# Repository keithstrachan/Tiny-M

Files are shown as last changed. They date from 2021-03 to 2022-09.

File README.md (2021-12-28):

# Tiny-M

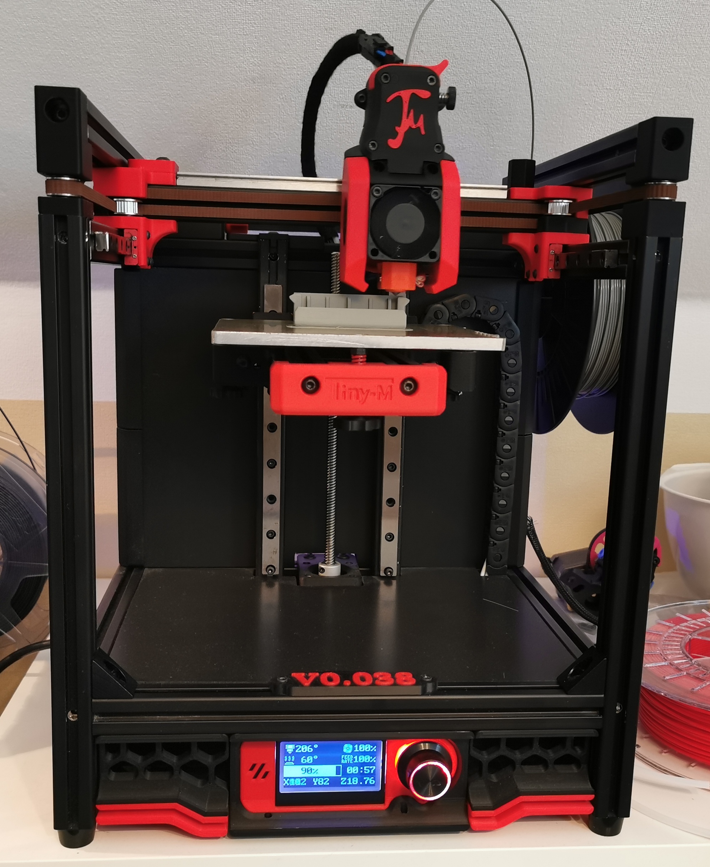
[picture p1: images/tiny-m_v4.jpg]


A compact printer with build volume: 150x150x150 mm

This is a Corona project.  
It is based on [Voron V0](https://github.com/VoronDesign/Voron-0) .  

Bowden and direct drive extruder using [CroXY's Sailfin](https://github.com/CroXY3D/Sailfin-Extruder), [Annex Engineering's Sherpa Mini](https://github.com/Annex-Engineering/Sherpa_Mini-Extruder) or [Bondtech's LGX Lite](https://www.bondtech.se/product/lgx-lite-extruder-custom/) are now available.  

### Current Version is V4:  

Latest source whole printer:  [Tiny-M V4 Onshape](https://cad.onshape.com/documents/1523b676d2485ac19dbd60ec/w/d40ca3d72ed1f4079efb6497/e/a8deb399653e35f8f0a5baa5)

Old source is available at [Tiny-M V3 Onshape](https://cad.onshape.com/documents/d2a24a4147c3d522115f6ea5/w/d8f44be5c0a081fbf527e154/e/debb6c2779e27f86389232d5).

This is my first project of this kind. Maybe something will be missing, is not well documented, or just messy. I apologize for that.  Join the [Discord](https://discord.gg/tmZkjWs) to meet other Tiny-M builders and have your questions answered.

## Why the whole thing?

I had many 3D printer parts in my pocket from my old no longer used printer. 
I cleared out my pocket and took what I had in the box without buying anything new.
After checking all parts, I recognize, that I could build a converted Voron V0 with this parts.

### Hardware

    - 2020 Nut 5 I-Typ alu profiles (6mm wide slot Misumi 2020 will work).  Must have 4.0-4.2mm hole at ends.  B-Typ can work with Helicoils to give a 5mm tapped end.
    - Nema 17 stepper motors
    - 1x 200mm MGN12H for X
    - 2x 200mm MGN9H for Y
    - 2x 200mm MGN12H for Z
    - FYSETC Cheetah V1.1b (TMC2209) or SKR Mini E3 with TMC2209
    - 24V everywhere

### BOM
DRAFT BOM is available now. Thanks to CookieSN!  An updated BOM for V4 is currently in review.

WARNING ! The store Funssor on aliexpress sell a V0 kit with pictures of my Tiny-M. He use picture from github. To be clear IT IS NOT a Tiny-M Kit. Please don't buy it if you want to build a Tiny-M.

### Build Tips
There are 3 versions of the XY-Joins.  V4 is recommended.

- V2 - use 2GT 20T pulleys - No Set Screw Hub
    - The outer diameter of the flanges from the pulleys for XY Joins will not fit.
    - You will need to grind the flanges to fit.
- V3 - use 2GT 20T toothed idler and no M5 Nuts
- V4 - split into 3 parts
    - removed one M5 screw for better alignment
    - optimized belt path to use E3D idler (10mm high) or chinese (9mm high)
    - some design changes
    - more rigid

Parts are best printed out of ABS or ABS+ with 0.4 nozzle with 0.48 extrusion width, 0.2-0.3 layer height, 5 top/bottom layers, 4 perimeters, 40% infill (triangular recommended).  Skirts can be printed out of pretty much any filament type.

There are drill and tapping jigs if you wish to drill and tap your extrusions yourself.  The drilled holes are for blind joints and aren't necessary if using corner brackets.

[Mark Hoy's Excellent Build Log](https://github.com/mark-hoy/tiny-m-build)

[Aku's Build Pix](https://photos.google.com/share/AF1QipNcXcmM3RKy_vv-VFk4SFu25SVPCTLMsn6qd6mMj0eABvdKW5LyGL7gtdgspUF8wQ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)

### User Mods
There are several user mod STLs in the [usermods](https://github.com/gsl12/Tiny-M/tree/master/usermods) directory.

#### V4 Mods
[Belted Z Mod](https://github.com/gsl12/Tiny-M/tree/master/usermods/belted_z_mod)

[190^3 Mod which uses Prusa mini bed plates](https://github.com/gsl12/Tiny-M/tree/master/usermods/190mm_prusa_mini_mod)

[All Metal Bed Undercarriage](https://github.com/gsl12/Tiny-M/tree/master/usermods/all_metal_bed_undercarriage)

[5mm Shoulder Screw Mod, (also works with B-Typ extrusions)](https://github.com/gsl12/Tiny-M/tree/master/usermods/shoulder_screw_mod)

[5mm Dowel Pin Mod](https://github.com/gsl12/Tiny-M/tree/master/usermods/5mm_idler_pins)

[Rear Cable Guide](https://github.com/gsl12/Tiny-M/tree/master/usermods/rear_cable_guide)

[Tophat Mod](https://www.prusaprinters.org/prints/64115-tiny-m-voron0-mod-tophead) - Note, an official tophat is in development.

#### V3 Mods
[Xile's Sherpa Direct Drive Toolhead](https://github.com/Annex-Engineering/Sherpa_Mini-Extruder/tree/master/Toolheads/Xile_Tiny_M)

[Ocho Camino's Sailfin Direct Drive Toolhead](https://github.com/CroXY3D/Sailfin-Extruder)

### Discord

The [CroXY Discord](https://discord.gg/tmZkjWs) has a tiny-m channel where several Tiny-M builders hang out.  Be sure to check the #tiny-m-faq channel

# Images

V3  



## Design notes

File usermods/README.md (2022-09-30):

### User mods

* tiny-m_tap_guide.stl : guide for tapping ends of 2020 extrusions (danielfmo)
* tiny-m_drill_guide.stl: drill guide for blind joint acccess holes (danielfmo)
* ab_drive_top_raised.STL : On some steppers the screws bottom out.  This thickens the plastic. (Xile)
* Knob_Wrench.stl : Tool to turn the tensioning knobs (Xile)
* Panel_Holder_1.STL : Panel holders keep panels from sagging - (Xile, modified from design by Anlin at Annex Engineering)
* PanelClip_v2_1.stl : Hold exterior panels on - (Xile, Modified from design by Anlin at Annnex Engineering)
* front_bed_mount_proud_text.stl : (Ocho Camino) Front of bed with text raised so you can do a filament swap.
* LRS-150_Mount.STL : Mount for Meanwell power supply (Xile)
* SKR_Mini_Mount.STL : Mount for SKR Mini (Xile)
* Raspi_Mount.STL : Mount for Raspberry Pi (Xile)
* Buck_Converter_Mount.STL : Mount for [Buck converter](https://smile.amazon.com/gp/product/B07N3QT628/ref=ppx_yo_dt_b_search_asin_title?ie=UTF8&psc=1]) for Raspberry Pi 5V (Xile) 
* Cover_No_Logo.STL : No logo version of screen cover
* door_handle: A handle for the enclosure door

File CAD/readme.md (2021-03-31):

# Current Version is V4:  

latest source whole printer:  [Tiny-M V4 Onshape](https://cad.onshape.com/documents/1523b676d2485ac19dbd60ec/w/d40ca3d72ed1f4079efb6497/e/a8deb399653e35f8f0a5baa5)

V4 folder includes separated CAD files for each V4 part.

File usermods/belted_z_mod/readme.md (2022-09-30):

### Belted Z Mod for 150mm and 190mm Tiny-M

@quasi

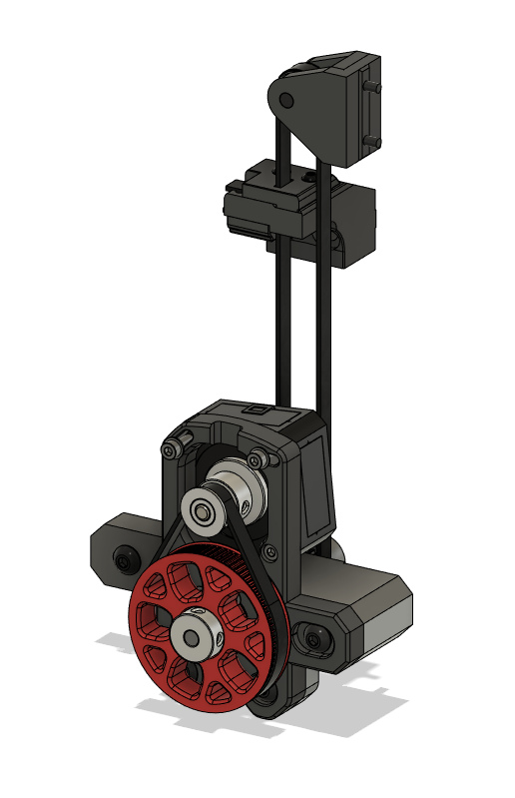
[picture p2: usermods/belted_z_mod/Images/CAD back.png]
Back


Modified from V0 belted z mod for Tiny-M printer, 2020 extrusions, and to upgrade some bolts from M3 to M5.

CAD shows a printed 80T gear because I copied that over from the V0 belted z files, but I used a metal 80T gear.

The M5x20mm screws need to be BHCS for clearance with 80T gear, but all other bolts can be either SHCS or BHCS.

Print the Bottom Frame Bracket 190.stl version if using this on a 190mm^3 Tiny-M

[sample printer.cfg changes](https://github.com/gsl12/Tiny-M/blob/master/usermods/belted_z_mod/beltedzstepper.cfg.txt)

#### BOM (US Sources)
##### Electronics	
- LDO NEMA17 42STH20-1004ASH	[PrintedSolid](https://www.printedsolid.com/collections/motors/products/ldo-nema-17-high-temp-voron-ldo-42sth20-1004ashvrn)  other 20 or a 25mm stepper 0.9 or 1.8 deg should work
##### Motion	
- F695-2RS Bearing [Amazon](https://www.amazon.com/F695-2RS-Bearing-5x13x4mm-Miniature-Bearings/dp/B07VMJLXLH)
- 1x 5mm shaft	78 mm	- I recommend measuring for yourself	[Amazon](https://www.amazon.com/Sydien-100mm-Solid-Stainless-Airplane/dp/B083LDBTLD)
- 1x 2GT Belt Loop (6mm wide) 188mm			[AliExpress](https://www.aliexpress.com/item/4000397043382.html)
- 1x 2GT Open Belt LL-2GT-6 (6mm wide) 10M			[AliExpress](https://www.aliexpress.com/item/32853559638.html)
- 1x 2GT 20T Pulley 6mm, 5mm Bore			[AliExpress](https://www.aliexpress.com/item/32995102911.html)
- 1x 2GT 16T Pulley 6mm, 5mm bore			[Amazon](https://www.amazon.com/gp/product/B01IMPM44O)
- 1x 2GT 80T Pulley 6mm, 5mm Bore			[AliExpress](https://www.aliexpress.com/item/32782605159.html)
- 1x 2GT 20T Toothed Idler 6mm, 5mm Bore		Alternate to 2 F695-2RS bearings	[AliExpress](https://www.aliexpress.com/item/32726309946.html) or better quality: [AliExpress](https://www.aliexpress.com/item/33023133633.html)
#### Hardware	
- Xx 5x10x0.5 Shim Ring			[AliExpress](https://www.aliexpress.com/item/32917948919.html) Qty as necessary.  
- 1x M3x5x4 Heatset Inserts		[AliExpress](https://www.aliexpress.com/item/4000232858343.html?spm=a2g0s.9042311.0.0.21164c4dGhWHhY)
- 2x M3 roll in T-nuts		[AliExpress](https://www.aliexpress.com/item/32805163712.html)
- 4x M5 roll in T-nuts			[AliExpress](https://www.aliexpress.com/item/32805163712.html)
- 2x M3 washer			
- 1x M5x40 SHCS			
- 3x M5x20 BHCS		These NEED to be BHCS for clearance with the 80T gear, all others can be SHCS or BHCS interchangeably	
- 1x M5x16 BHCS			
- 3x M3x12 SHCS			
- 1x M3x20 SHCS

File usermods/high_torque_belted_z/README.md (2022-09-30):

### High Torque Belted Z

- @AgentL3r#0333

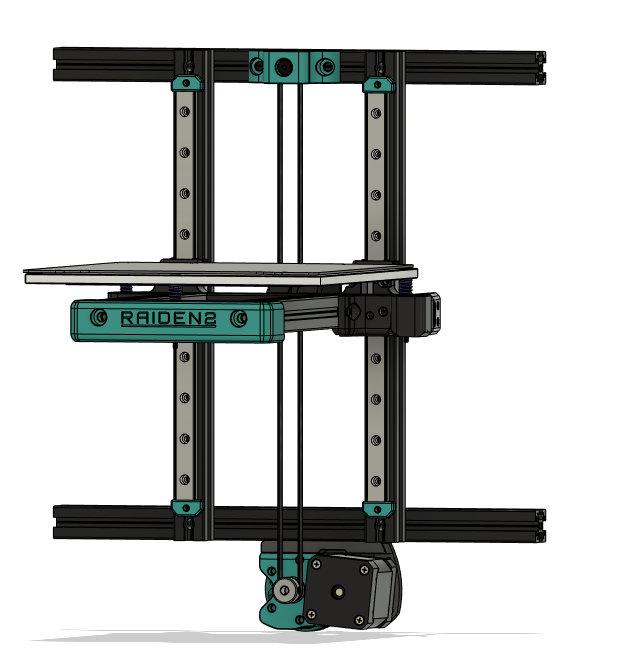
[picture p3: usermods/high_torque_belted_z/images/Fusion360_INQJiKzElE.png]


## Features and Rationale
- Allows for any size of NEMA17 motor to be used, increasing versatility and mitigates the need for slimline/pancake motors 
- Motors with higher detent torques can be used to prevent bed drop on power loss (after 4:1 gearing)
- Gearbox is mounted under the electronics enclosure leading to more space for electronics mounting
- Compatible with both 190mm³ and 150mm³ builds **MUST USE MODIFIED PARTS BY nehiLo#1732**
- Shoulder screw compatible upper z idler
- Arguably less Z artifacting due to no leadscrew
  
## Bill of Materials

Fasteners
- M3x5x4 mm threaded insert x5
- M3 washer (1mm) x3
- M3 shim (0.5mm) x3
- M3x6 BHCS x4
- M3x10 SHCS x4
- M3x20 SHCS x6
- M5 t-nut x7
- M5x10 BHCS x4
- M5x20 BHCS x2
- M5x28 BHCS OR M5x16 SHOULDER SCREW with 5mm shoulder x1
- M5x60 dowel pin

Motion
- F695-2RS bearing x2
- 20T 2GT pulley x2
- 80T 2GT pulley x1 (CAN ALSO USE PRINTED VORON M4 80T)
- 188mm 2GT 6mm belt loop
- some 2GT 6mm belt
- 20T 5mm bore idler

Electronics
- NEMA17 motor

## Assembly
It is best to refer to the CAD  model for guidance on how to build this system.

**Gearbox:**
Insert the four heatset inserts into the back of the shaft guide and press-fit the F695-2RS bearing as follows:
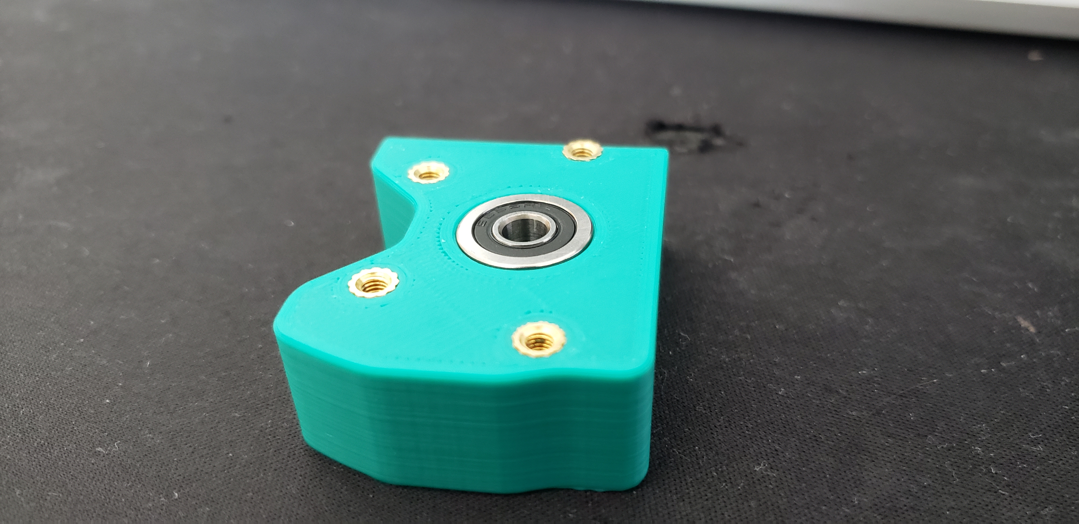
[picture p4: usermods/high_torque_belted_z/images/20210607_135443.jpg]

Press fit an F695-2RS bearing onto the motor plate.

Attach the motor plate to the bottom of the 2020 extrusion on your printer using two M5x10mm screws and two M5 t-nuts. Ensure you use the flat edge and a pair of calipers to correctly position the motor plate so that the pin is centered.

Attach the shaft guide using four M3x20 screws.

Insert the 5x60mm shaft through the motor plate and shaft guide, ensuring it spins freely in the bearings.

The pulleys can now be attached:

80T pulley --> printed spacer --> F695-2RS --> F695-2RS  --> 0.5mm shim --> 20T pulley

Tighten all grub screws.

Insert the remaining 20T pulley onto the shaft of the NEMA17 motor. Screw the motor to the motor plate using M3x10 screws (not fully tight as you'll need the motor to swivel for tension) and an M3 washer. During this, ensure the belt loop wraps around the 20T and 80T pulley. You can now tension the pulley and fully tighten all motor mounting screws. The gearbox is now complete.

**Idler:**
The upper idler is simple to assemble with a 20T idler sandwiched between two 0.5mm shims. Attach this to the top 2020 extrusion as per the CAD model.

**Tensioner:**
Insert the final heatset insert into the hole at the TOP of the tensioner.

Attach the tensioner to the back of the Z carriage using the M5x20mm screws and two M5 t-nuts. Positioning at this point isn't important.

Insert the two M3x20 screws into the tensioner. At this point, you can route the belt. 

The belt will wrap around the M3x20 screws so that the teeth indexes with itself, creating a very secure hold. Place the printed block in the center of the tensioner with the hole facing up.

Using the M3x6mm screws, secure the backplate.

Finally, use an M3x10 screw to tension the belt by pressing the printed block.

This assembly is fiddly and takes a while to get assembled - especially the belt tension. The system works very well and has given me excellent results.

Double check your spacing for everything prior to turning on the system - refer to the CAD if in doubt.

For any questions, feel free to get in touch with me on the TinyM Discord.

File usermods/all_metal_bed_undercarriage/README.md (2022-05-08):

### All Metal Bed Undercarriage

- @Ocho Camino

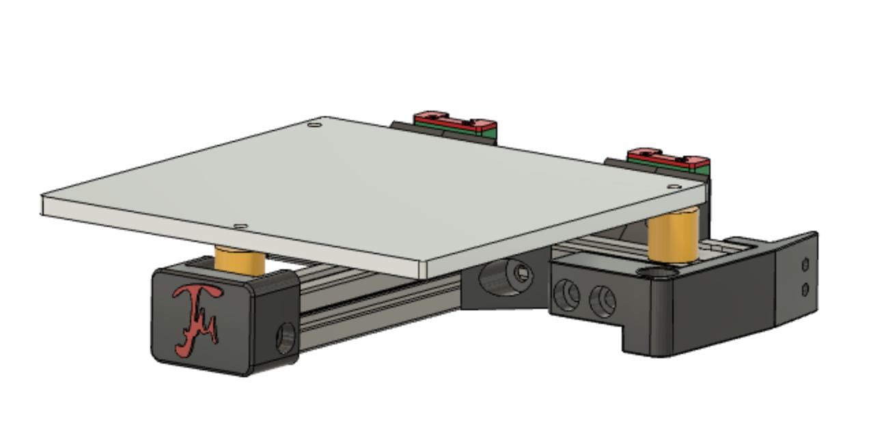
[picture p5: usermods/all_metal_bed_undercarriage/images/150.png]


## Rationale
The existing bed mounts are made of ABS and flex somewhat.   Making the entire bed undercarriage out of metal greatly reduces this flex.

## Status

  Alpha.  Still testing.  There could be some changes.
  
## BOM

150mm Bed:
- 1x HFSB5-2020-160-AH80-AV10-BV150
- 1x HFSB5-2020-160 (with 4 3mm clearance holes drilled for the MGN12 mount screws. Use MGN12_drill_jig.stl)
- 1x HFSB5-2020-133-RTP-AV10 (Misumi). 

190mm Bed:
- 1x HFSB5-2020-200-AH100-AV10-BV190 
- 1x HSFB5-2020-200 (with 4 3mm clearance holes drilled for the MGN12 mount screws.  Use MGN12_drill_jig.stl)
- 1x HFSB5-2020-173-RTP-AV10

Common:
- 6x Openbuilds Angle Brackets [Openbuilds](https://openbuildspartstore.com/black-angle-corner-connector/) [Ali Express](https://www.aliexpress.com/item/32899575950.html)
- 3x 16mm long silicone bed mounts [Amazon](https://smile.amazon.com/dp/B07RZKF8MB?psc=1&ref=ppx_yo2_dt_b_product_details)
- 3x Bed Adjusters (reuse existing) [Ali Experss Style B or D](https://www.aliexpress.com/item/4000421280308.html)
- 3x 45mm (or 50mm) FHCS screws.  45s protrude only 2.3 mm below the extrusion, so 50 is probably better.
- 4x M3 washers (at least 6mm OD) - [ALT Ali Bling](https://www.aliexpress.com/item/32968161596.html)
- 4x M3x8 SHCS (might need M3x10 with the Alt Ali Bling)
- 11x M5x6 BHCS
- 1x M5x12 SHCS
- 1x M5x16 SHCS

## Assembly

Print the parts (ok, it's not all metal, but the load bearing parts are). The nosepiece can be printed with a filament swap for a contrasting color for the logo.  

Note the rear two holes on the bed are in slightly different positions than on stock Tiny-M.  They are 12mm from the rear.
Use the template (TBD) to drill the two countersunk M3 holes.   

The underbed assembly is made of 3 pieces of 2020.  The rear piece attaches to the MGN12 cars.  The middle piece sisters to the rear piece and also supports the bed at each end in the rear.  The front piece is the forward pointing spar that supports the bed at the middle in the front.

The rear 2020 piece will need to be drilled with 4 3mm clearance holes to attach it to the MGN12 car.  Use the MGN12_drill_jig.stl to drill these holes, from each side of the 2020.

If you ordered the other 2020 parts without Misumi drilling for you, you will need to use the drill guide. The middle 2020 that is is sistered to the rear 2020 piece needs a 3mm vertical clearance hole 10mm from each end, and a 5mm horizontal clearance hole 30mm from each end (middle_front_drill_jig.stl).   Additionally that piece needs a 5mm horiztonal clearance hole centered on the extrusion - use middle_jig.stl centered on the extrusion.

The front piece is tapped M5 at the rear and has a 3mm clearance hole drilled vertically 10mm from the front of it (middle_front_drill_jig.stl).

Assemble the middle and front spar 2020 pieces to form a tee.   The two angle brackets that support the forward spar can be any type of angle bracket. Make sure this connection is solid and doesn't twist or flex.   Attach the spar to the tapped hole with a M3x8 BHCS for more rigidity. 

The Openbuilds corner brackts screw into the top screw holes of the MGN12H cars. Attach them to the rear 2020 piece.  The rear 2020 is attached to the lower screw holes of the MGN12H car via M3x16 SHCS.

Attach the tee piece to the rear piece with 2 M5x6 BHCS

The rest of the parts assembly should be straightforward.

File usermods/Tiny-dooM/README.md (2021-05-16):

### Tiny-dooM

- @Ocho Camino

An outer enclosure around the Tiny-M printer.  This has only been designed in CAD.  Nothing has been done IRL.

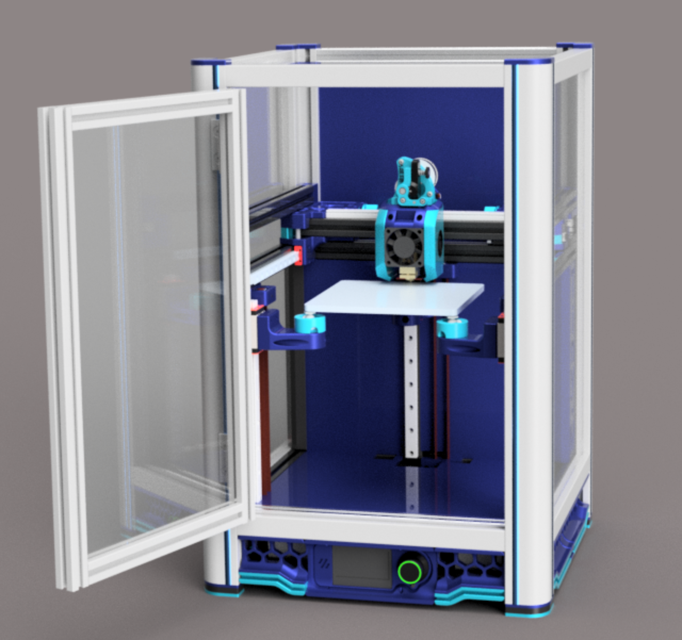
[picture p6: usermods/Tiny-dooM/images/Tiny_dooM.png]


#### BOM

Nothing is changed from the default Tiny-M BOM.  However you will need to drill 2 blind joint access holes in the 4 z corner extrusions.  Those holes should be approx 30mm from the ends and face fore and aft.  They are used to attach the Tiny-M to the dooM frame.

For a 190^3 Tiny-dooM add 50mm to every extrusion length

- 4x HFSR5-404020-500 Corner Posts
- Non-smooth faced extrusion option
  - 8x HFS5-2020-260 Top and bottom horizontals
  - 2x HFS5-2020-217 Front door horizontals
  - 2x HFS5-2020-408 Front door verticals
- Smooth faced extrusion option
  - 2x HFS5-2020-260 Top and bottom rear horizontals (Slots exposed for mounting things)
  - 3x HFSF5-2020-260 - Bottom front, left and right horizontals
  - 3x HFST5-2020-260 - Top front, left and right horizontals
  - 2x HFSF5-2020-217 Front door horizontals
  - 2x HFSF5-2020-408 Front door verticals - you will need to drill holes for hinges and handle
- 2x Hinges [Zyltech](https://www.zyltech.com/aluminum-swing-door-hinge-for-20mm-extrusion-w-mounting-hardware/) alt: HHPNL5-SST hinges
- 24x Internal Corner Brackets [Zyltech](https://www.zyltech.com/t-slot-l-type-90-degree-2020-inside-bracket-12-pack/)
- Door Catch TBD
- Optional: Ninjaflex or similar TPU for feet

Total Hardware Cost for 150 Tiny-dooM (no panels): ~$85

#### Printed Parts

- 4x Top trim pieces
- 4x Feet.  Optionally print black portion using Ninjaflex or similar TPU by filament swap.  Use XX% infill
- TBD Panel retention:  Double pane?  In slot or slight inset from frame?

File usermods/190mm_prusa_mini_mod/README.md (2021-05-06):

### 190^3 Build volume which can use the Prusa Mini Bed Plate.

- @Ocho Camino & @AgentL3r
- Skirts by @AgentL3r

The changes for a 190^3 build volume are fairly simple.   
- All frame extrusions need to be 50mm longer
   * 11x 2020 310mm  (note one more than normal Tiny-M.  This is used as a cross brace about halfway up in the front to stiffen the frame)
   * 4x	2020 350mm
   * 2x	2020 300mm
- All bed extrusions need to be 40 mm longer
   * 3x	2020 170mm
- 1X 250mm MGN12H for X (RobotDigg SUS 440C highly recommended) 
- 2x 250mm MGN9H for Y 
- 2X 250mm MGN12H for Z
- 250mm TR8x4 leadscrew
- Mic6 bed should be 190x190x6mm.  Template for drilling are in the STLs subdir here.
- Bed heater should be 150x150mm.   [Keenovo or AliExpress](https://www.aliexpress.com/item/4000271859036.html?spm=a2g0s.9042311.0.0.27424c4dSLLDSs)
- Three parts need to be 40mm wider.  The front nosepiece and the upper and lower Z supports.  They are in the STLs subdir here
- Skirts are changed.  STLs and CAD by @AgentL3r are here

Note that the nosepiece is modded with proud text, so you can print it text up and do a filament swap for contrasting text.  The holes in the nosepiece have a membrane for printability that must be drilled out 5mm.

If you wish to use blind holes, the extrusion BOM:
- 2x HFSB5-2020-170-TPW		Z carriage.
- 1x HFSB5-2020-170-AH40-BH130	 Z carriage. 
- 2x HFSB5-2020-300-LCV-RCV		Vertical extrusions.
- 1x HFSB5-2020-310	X axis extrusion. 
- 3x HFSB5-2020-310-TPW	Lower front and upper left/right extrusions. 
- 4x HFSB5-2020-310-TPW-AH274		Left and right extrusions. 
- 2x HFSB5-2020-310-TPW-AH93.5-BH216.5	Horizontal Z extrusions.
- 2x HFSB5-2020-350-TPW-RCH-AP60		Front vertical extrusions. 
- 2x HFSB5-2020-350-TPW-RCH-AH60		Rear vertical extrusions.

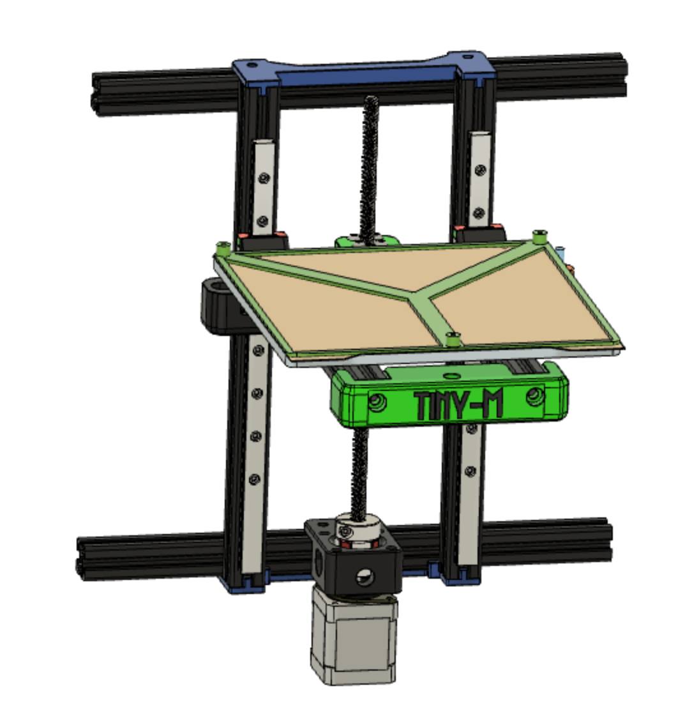
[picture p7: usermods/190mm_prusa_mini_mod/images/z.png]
190^3 Z Assembly


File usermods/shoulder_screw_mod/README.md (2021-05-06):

### Shoulder Screw Mod

by Ocho Camino

This is a mod to use shoulder screws instead of regular metric screws as the shafts for the idlers to ride upon.  

#### Rationale

Shoulder screws are machined to specified dimensions vs screws which are undersized and often have a rough surface.  With undersized screws the contact area of the screw to the inner race of the bearing is much less (ideally a line), creating excessive Hertzian contact stress.  This is hard on the bearing and can create imprecision in the motion of the machine.

#### Description

This mod either uses Misumi 5mm shoulder screws which have M3 threads on the end, or McMaster or other shoulder screws which have M4 threads.  The thread lengths are important on the McMaster M4 version, so if substituting other sources you may need to remove some thread if it's too long and bottoms out.

On the four corners of Tiny-M the ends of the 2020s are tapped M5 for M5 screws.  If using Misumi shoulders, you will need thread adapters.   If using M4 shoulders you will need M4 Helicoils

Print the replacement parts in the STL directory here.

Total cost of this mod is about $25-$30.

#### MISUMI M3 THREADED SHOULDERS
  * 6x 5mmx30 Shoulder Screws M3 Threads, Misumi [SMSB5-30](https://us.misumi-ec.com/vona2/detail/110300249140/?ProductCode=SMSB5-30)
  * 4x 5mmx20 Shoulder Screws M3 Threads, Misumi [SMSB5-20](https://us.misumi-ec.com/vona2/detail/110300249140/?ProductCode=SMSB5-20)
  * 4x M3-M5 308 Type Thread Adapters, AliExpress [M3-M5 308](https://www.aliexpress.com/item/32817733610.html)
  * 2x M3 Tee Nuts

Print the replacement parts, except the M4 versions in the STL directory here.  Install the thread adapters on the 4 M5x30 shoulder screws and secure with Loc-Tite.   These may then be threaded into the tapped M5 hole on the end of the 2020 vertical corner extrusions.  The Tee nuts accept the shoulder screw for the front idler on the AB drives
 
#### FILASTRUDER OR MCMASTER M4 THREADED SHOULDERS
  * 4x 5mmx30 Shoulder Screws, 5-9mm long M4 threads for corners, [Filastruder](https://www.filastruder.com/products/shoulder-screws-bolts?_pos=1&_sid=c5a60b2bd&_ss=r&variant=32520243380295) or [McMaster 92981A055](https://www.mcmaster.com/92981A055/)
  * 2x 5mmx30 Shoulder Screws 5mm long M4 threads for AB drives, [Filastruder](https://www.filastruder.com/products/shoulder-screws-bolts?_pos=1&_sid=c5a60b2bd&_ss=r&variant=32520243380295) or [McMaster 90278A376](https://www.mcmaster.com/90278A376/)
  * 4x 5mmx20 Shoulder Screws, 5-9mm long M4 threads for XY Joins, [Filastruder](https://www.filastruder.com/products/shoulder-screws-bolts?_pos=1&_sid=c5a60b2bd&_ss=r&variant=16712533868615) or [McMaster 92981A042](https://www.mcmaster.com/92981A042/)
  * 1x M4 Helicoil kit, AliExpress [M4x0.7](https://www.aliexpress.com/item/4001157165014.html) or [McMaster 91732A946](https://www.mcmaster.com/91732A946/)
  * 2x M4 Tee Nuts

Print the replacement parts (the M4 versions) in the STL directory here.  Install M4 helicoils in the 4 corner 2020 extrusions.   The Tee nuts accept the shoulder screw for the front idler on the AB drives 

#### EU Folks using 20x20 B-type groove 6 and M4 THREADED SHOULDERS
  * 4x 5mmx30 Shoulder Screws, 8mm long M4 threads for corners, Drasse [460119196](https://www.drabbe.nl/p/iso-7379-5-m4-30/100351/)
  * 2x 5mmx25 Shoulder Screws 8mm long M4 threads for AB drives, Drasse [460119221](https://www.drabbe.nl/p/iso-7379-5-m4-25/100350/)
  * 4x 5mmx20 Shoulder Screws, 8mm long M4 threads for XY Joins Drasse [460119215](https://www.drabbe.nl/p/iso-7379-5-m4-20/100349/)
  * 4x M4-M6 308 Type Thread Adapters, AliExpress [M4-M6 308](https://www.aliexpress.com/item/32817733610.html)
  * 2x M4 Tee Nuts

Print the replacement parts, except the M4 versions in the STL directory here.  Install the thread adapters on the 4 M5x30 shoulder screws and secure with Loc-Tite.   These may then be threaded into the tapped M6 hole on the end of the 2020 B-type groove 6 vertical corner extrusions. The Tee nuts accept the shoulder screw for the front idler on the AB drives

Note, the 5mm shoulders with M4 threads can be sourced from China.  [one possible source - not verified](https://www.aliexpress.com/item/1005001698010943)

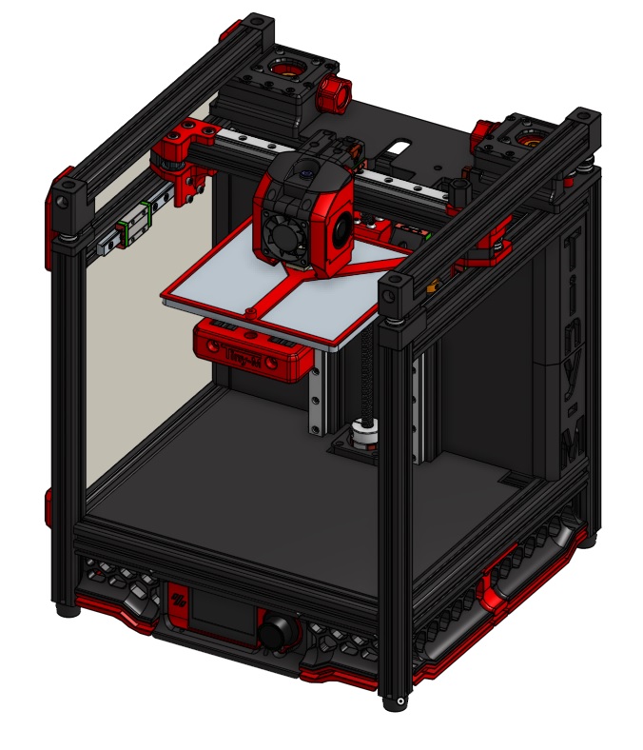
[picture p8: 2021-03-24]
images/CAD_V4.jpg

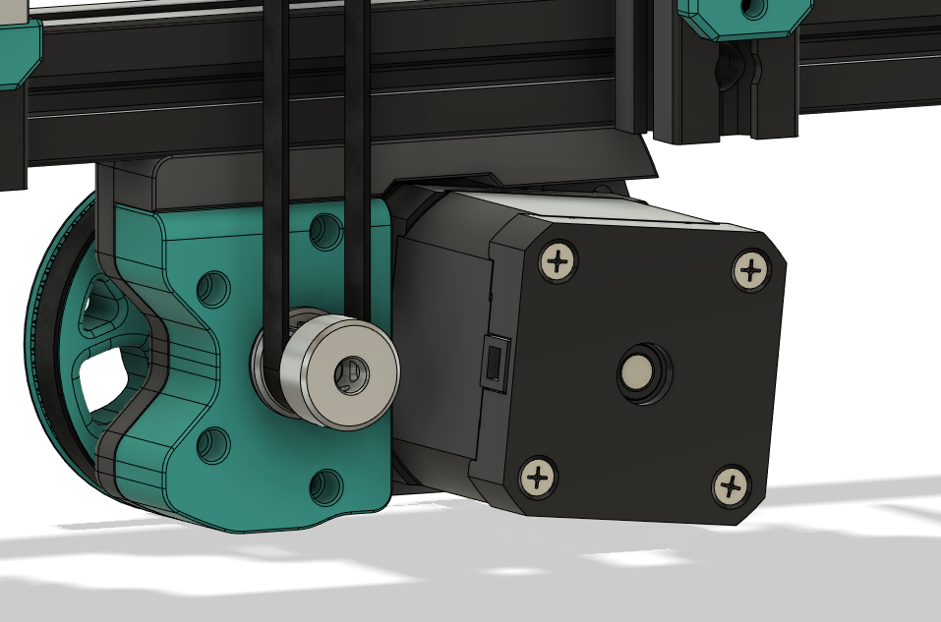
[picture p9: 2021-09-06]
usermods/high_torque_belted_z/images/Fusion360_5fomUjJK1f.png

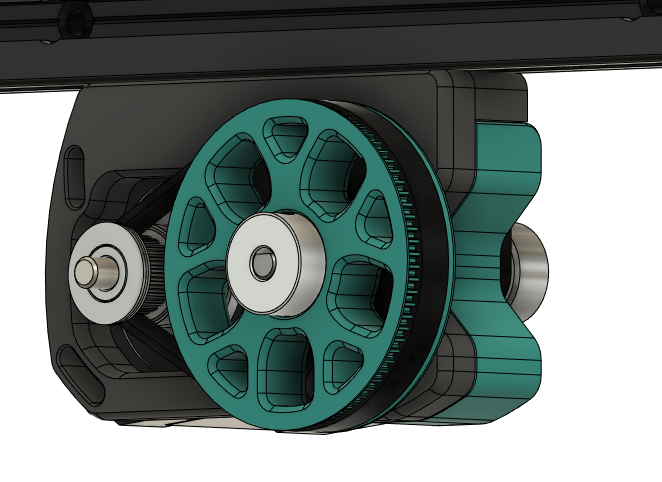
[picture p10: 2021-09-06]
usermods/high_torque_belted_z/images/Fusion360_azjq1ihh6n.png

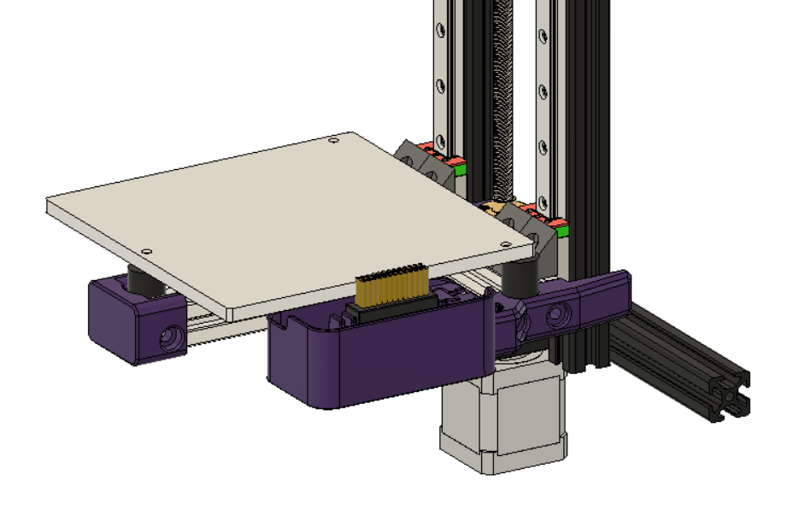
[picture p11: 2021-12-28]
usermods/almost_all_metal_undercarriage_with_purge_bucket/Images/cad_image.png

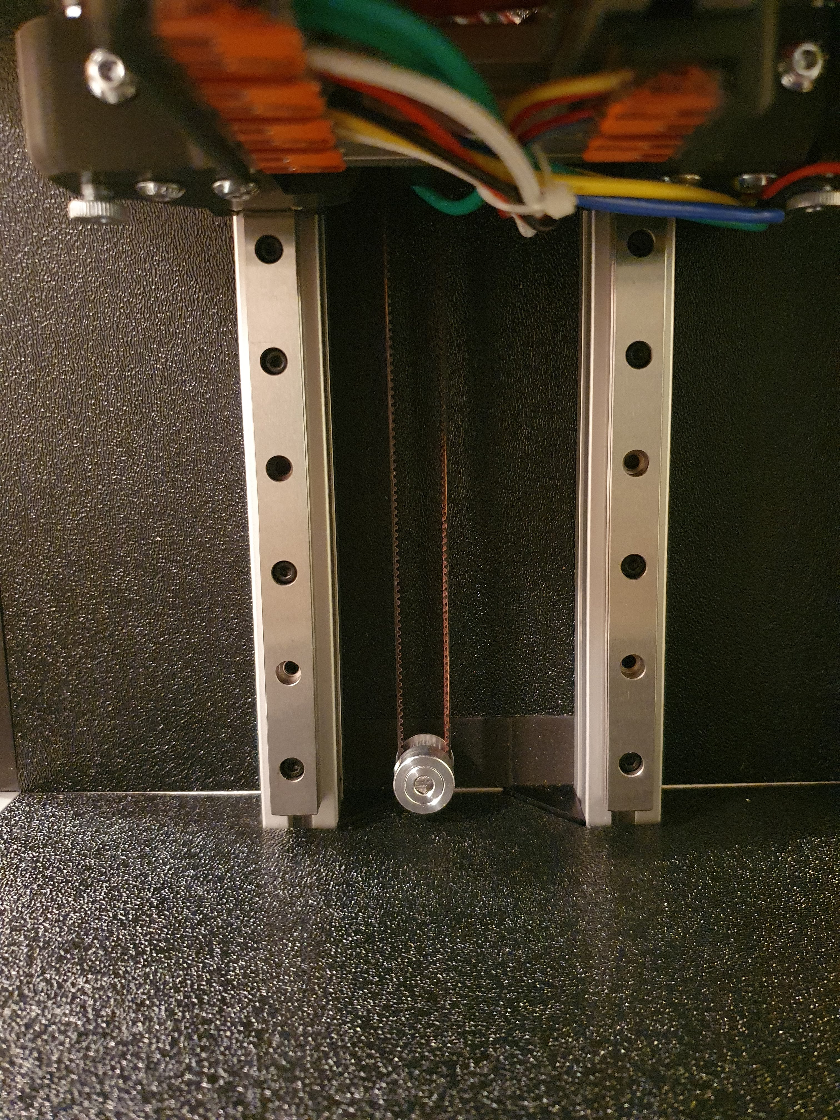
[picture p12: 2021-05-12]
usermods/belted_z_mod/Images/Under bed.jpg

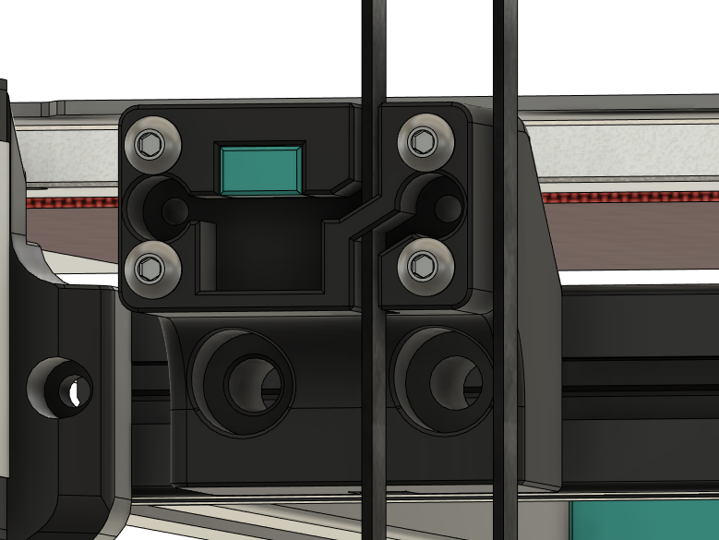
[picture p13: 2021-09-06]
usermods/high_torque_belted_z/images/Fusion360_2svyNtLjEN.png

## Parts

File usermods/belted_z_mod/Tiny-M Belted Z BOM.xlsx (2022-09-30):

 | Component | Quantity | Notes | Vendor (US) | Link (US)
Electronics | LDO NEMA17 42STH20-1004ASH | 1 |  | PrintedSolid | https://www.printedsolid.com/collections/motors/products/ldo-nema-17-high-temp-voron-ldo-42sth20-1004ashvrn
Motion | F695-2RS Bearing | 5 |  | Amazon | https://www.amazon.com/F695-2RS-Bearing-5x13x4mm-Miniature-Bearings/dp/B07VMJLXLH
 | 5mm shaft | 78 mm | I recommend measuring for yourself | Amazon | https://www.amazon.com/Sydien-100mm-Solid-Stainless-Airplane/dp/B083LDBTLD?s=hi
 | GT2 Belt Loop (6mm wide) 188mm | 1 |  | AliExpress | https://www.aliexpress.com/item/4000397043382.html
 | GT2 Open Belt LL-2GT-6 (6mm wide) - 10M | 1 |  | AliExpress | https://www.aliexpress.com/item/32853559638.html
 | GT2 20T Pulley 6mm, 5mm Bore | 1 |  | AliExpress | https://www.aliexpress.com/item/32995102911.html
 | GT2 16T Pulley 6mm, 5mm bore | 1 |  | Amazon | https://www.amazon.com/gp/product/B01IMPM44O/ref=ppx_yo_dt_b_asin_title_o05_s00?ie=UTF8&psc=1
 | GT2 80T Pulley 6mm, 5mm Bore | 1 |  | AliExpress | https://www.aliexpress.com/item/32782605159.html
 | GT2 20T Toothed Idler 6mm, 5mm Bore | 1 | Alternate to 2 F695-2RS bearings | AliExpress | https://www.aliexpress.com/item/32726309946.html
Hardware | 5x10x0.5 Shim Ring | Varies |  | AliExpress | https://www.aliexpress.com/item/32917948919.html
 | M3x5x4 Heatset Inserts | 1 |  | AliExpress | https://www.aliexpress.com/item/4000232858343.html?spm=a2g0s.9042311.0.0.21164c4dGhWHhY
 | M3 roll in T-nuts | 2 |  | AliExpress | https://www.aliexpress.com/item/32805163712.html
 | M5 roll in T-nuts | 4 |  | AliExpress | https://www.aliexpress.com/item/32805163712.html
 | M3 washer | 2
 | M5x40 SHCS | 1
 | M5x20 BHCS | 3 | These NEED to be BHCS for clearance with the 80T gear, all others can be SHCS or BHCS interchangeably
 | M5x16 BHCS | 1
 | M3x12 SHCS | 3
 | M3x20 SHCS | 1

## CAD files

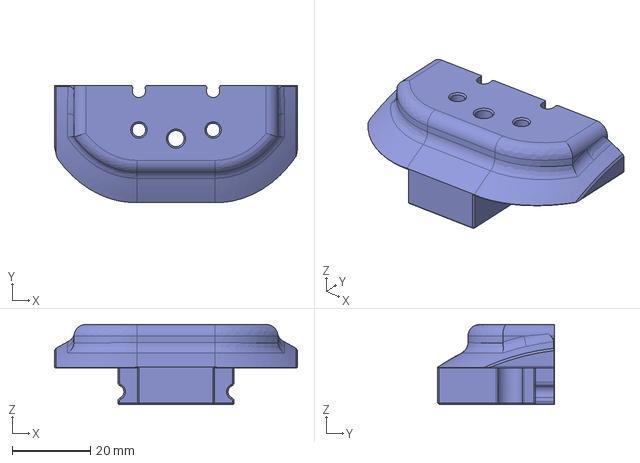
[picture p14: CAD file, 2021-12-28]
CAD/V4/bw_dd_sch_wing_v12_lgx_lite.step
62.2 x 30.0 x 20.5 mm

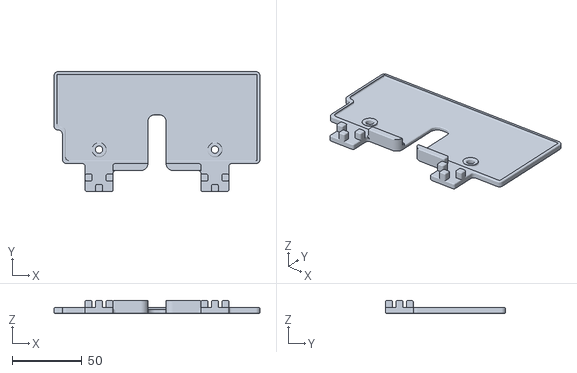
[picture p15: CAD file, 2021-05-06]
STLs/essentials/Bed/z_positioner_upper.stl
147.6 x 86.0 x 9.00

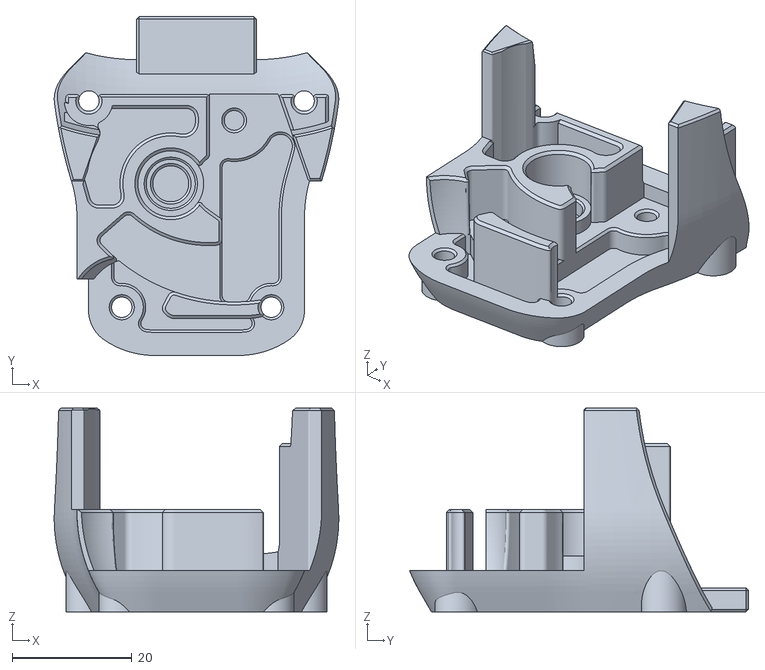
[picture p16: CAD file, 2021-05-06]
STLs/essentials/Gantry/X_Axis/X_Carriage/mini_AB_parts/printed_parts_MGN12_v4 - mini_ab - front_logo.stl
47.6 x 56.7 x 34.0

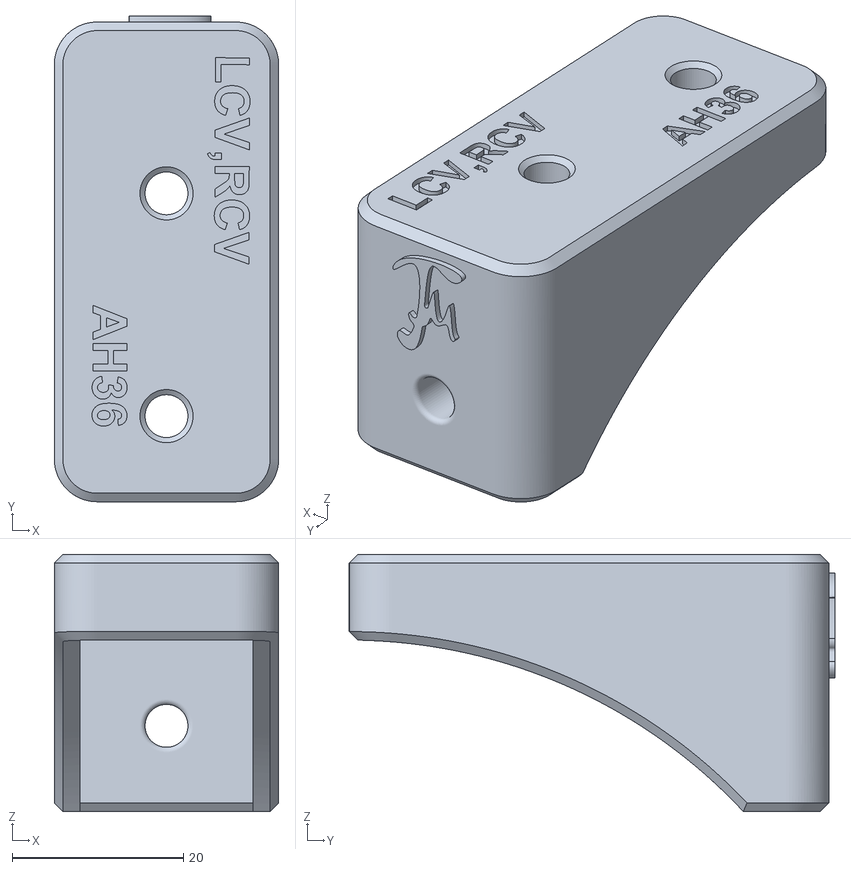
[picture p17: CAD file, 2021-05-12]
STLs/essentials/Tools/Drill_Tap_Jig_B_.stl
26.2 x 56.7 x 30.0

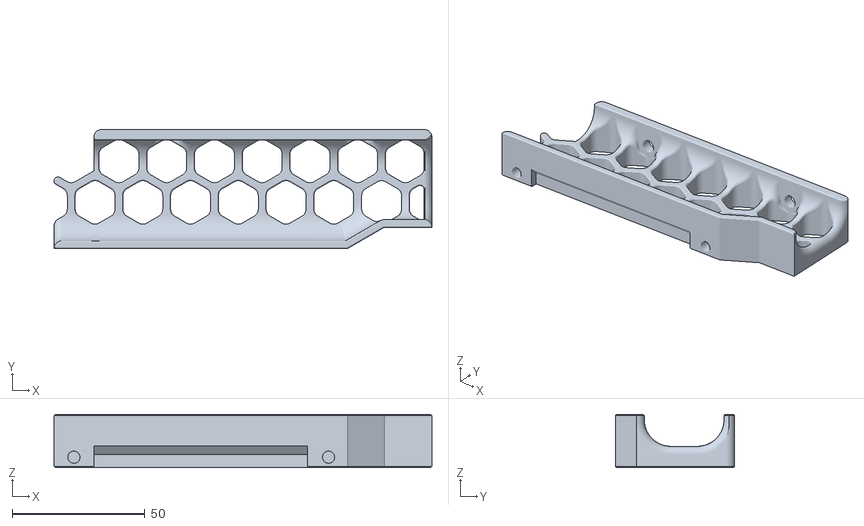
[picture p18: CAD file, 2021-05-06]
usermods/190mm_prusa_mini_mod/STLs/skirt_side_right_x2.stl
142.5 x 44.9 x 20.0

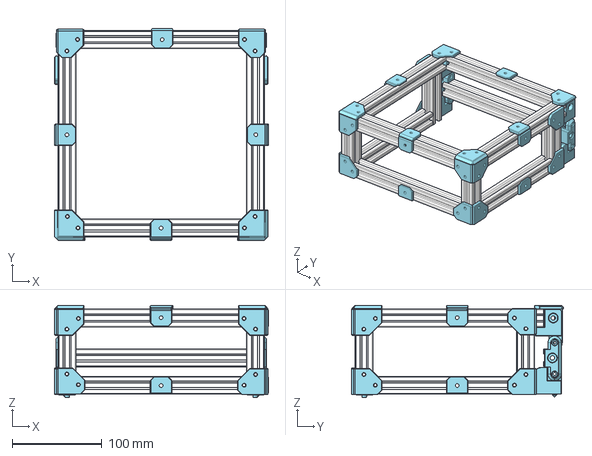
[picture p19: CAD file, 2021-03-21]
usermods/2020_Hinged_TopHat_Print/2020_Hinged_TopHat_CAD.step
238.7 x 236.5 x 103.1 mm

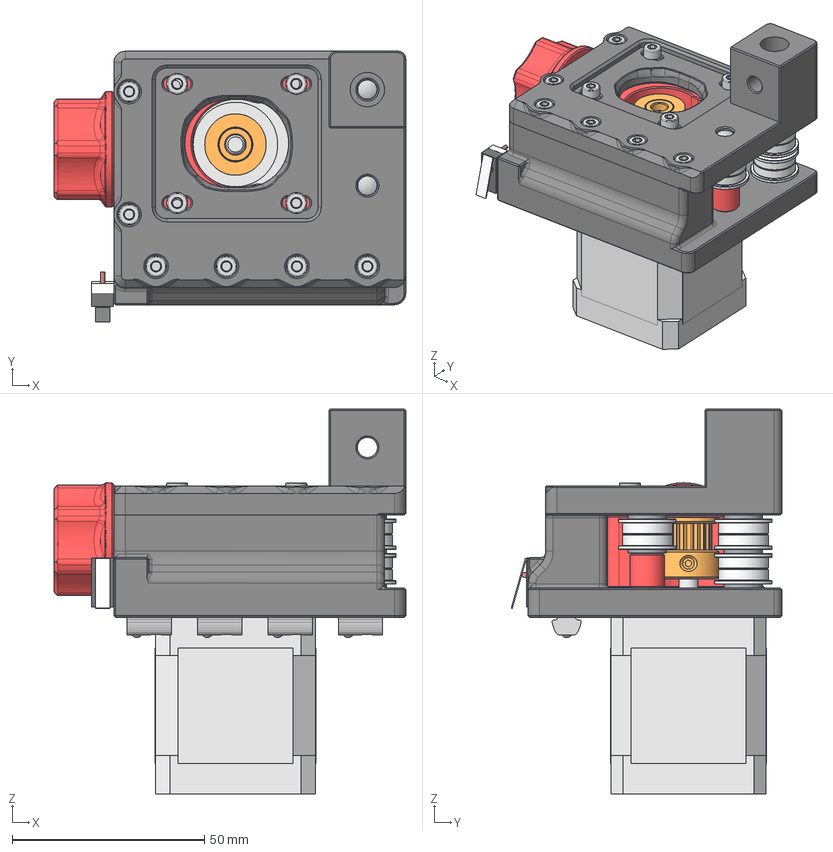
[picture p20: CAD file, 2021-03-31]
usermods/5mm_idler_pins/CAD/ab_drive_unit_right_V4 v4.step
91.5 x 70.4 x 100.2 mm
DIN 912 M3x35 x 8
M3-T-Nut x 4
DIN 912 M3x30 x 2
F695-2RS x 6
DIN 988 5x10x1 Shim Ring x 5
b_drive_right_bottom_V4
DIN 934 M3 x 2
D2F-5L
Motor 17HS19-2004S
GT2_20T
[a]_b_drive_right_tensioner_V4
[a]_b_drive_knop_V4
[a]_ab_drive_spacer_9mm
b_drive_right_top_V4
91595A376_32mm_METRIC ALLOY STEEL DOWEL PIN x 2

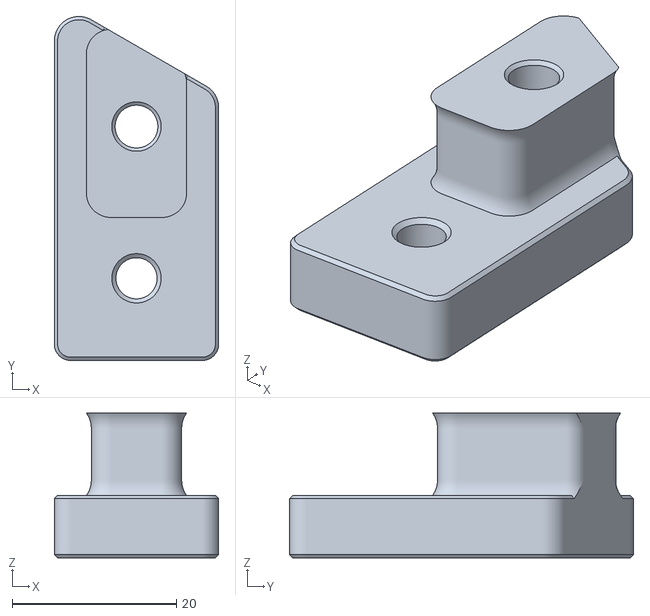
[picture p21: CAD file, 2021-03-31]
usermods/5mm_idler_pins/STL/front_idler_left_bottom_V4.stl
20.0 x 41.8 x 17.6

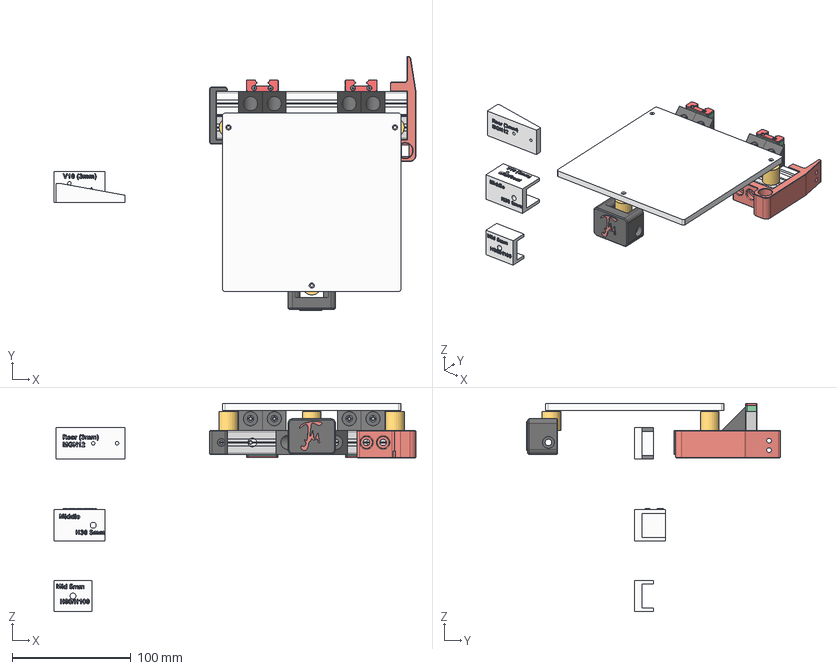
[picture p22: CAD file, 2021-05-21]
usermods/all_metal_bed_undercarriage/CAD/150mm.step
304.4 x 213.7 x 175.0 mm
Bed
MGN12H, LINEAR GUIDE BLOCK x 2
Silicone Bed Spacer
End Cap
Nameplate
HFSB5-2020-160-LCV-RCV-AH30-BH80-CH130
HFSB5-2020-160-Drilled
Z Touch and Chain Mount
Jigs

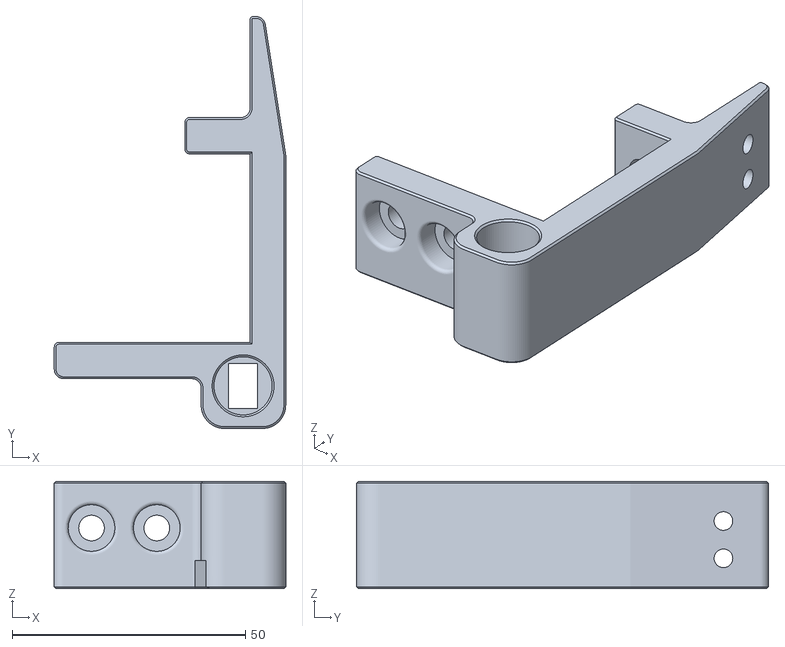
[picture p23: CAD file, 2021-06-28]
usermods/all_metal_bed_undercarriage/STL/Z_Touch_and_Chain_Mount.stl
49.6 x 88.3 x 23.0

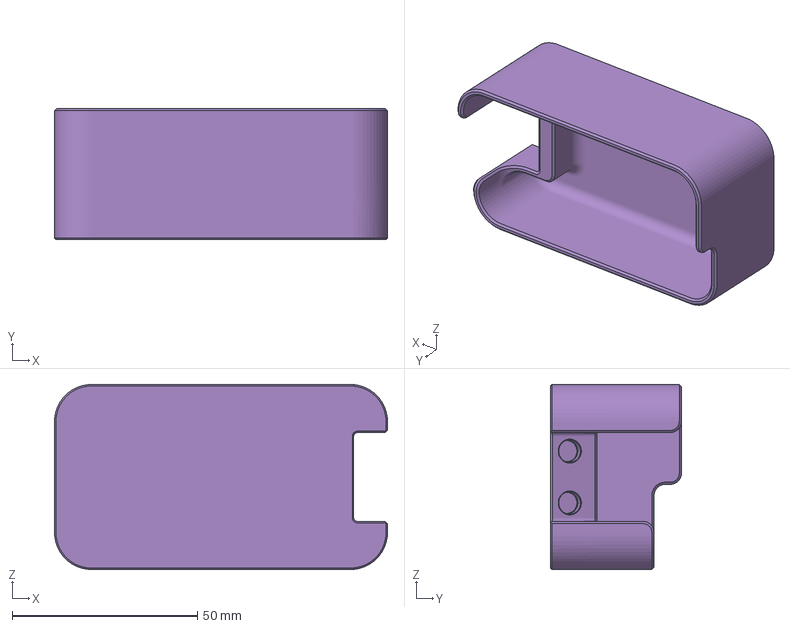
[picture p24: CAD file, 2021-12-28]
usermods/almost_all_metal_undercarriage_with_purge_bucket/STLs/brush_bucket.3mf
90.0 x 35.4 x 50.0 mm

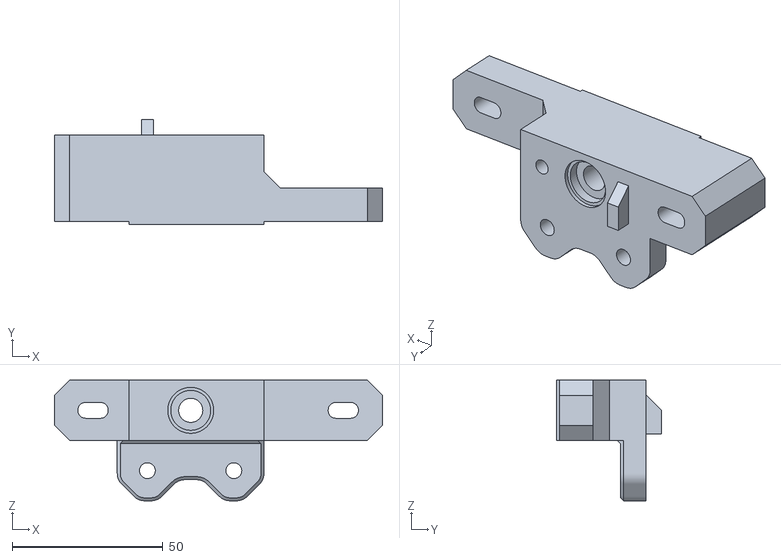
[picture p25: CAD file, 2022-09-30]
usermods/belted_z_mod/STLs/Bottom Frame Bracket.stl
108.8 x 34.7 x 40.0

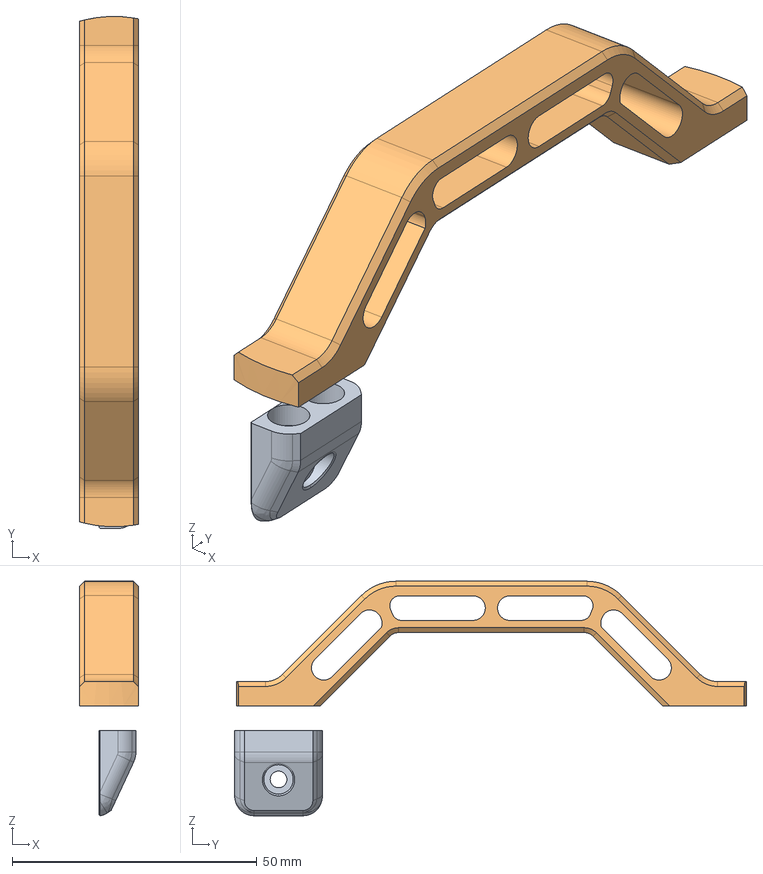
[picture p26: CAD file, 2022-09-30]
usermods/door_handle/CAD/TinyM Handle v3.step
12.0 x 104.6 x 47.9 mm
Door_Latch
Door_Handle

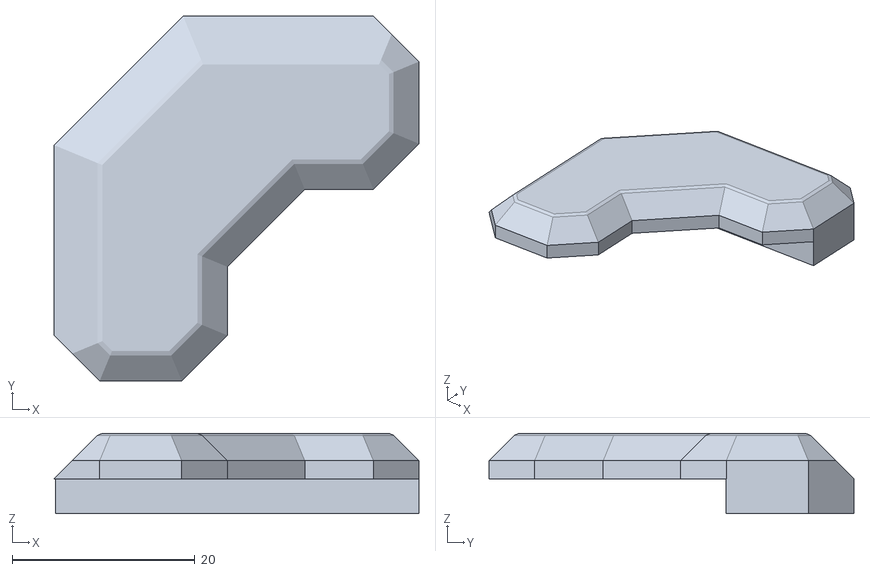
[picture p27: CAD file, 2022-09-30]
usermods/door_handle/stl/corner_door_flat(Mirror).stl
40.0 x 40.0 x 8.80

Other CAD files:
STLs/essentials/Gantry/X_Axis/X_Carriage/printed_parts_MGN12_v4 - bw_dd_sch_wing_lgx_lite.stl
usermods/DrillGuides/tiny-m_drill_guide.step.step
usermods/front_bed_mount_proud_text.stl
usermods/high_torque_belted_z/STLs/150mm ver/beltztens150.stl
CAD/V3/ass_x_carriage_E3DV6.step
CAD/V4/Drill Tap Jigs v4.f3d
CAD/V4/Drill Tap Jigs v4.step
STLs/essentials/Bed/z_position_lower.stl
STLs/essentials/Gantry/X_Axis/X_Carriage/mini_AB_parts/printed_parts_MGN12_v4 - bw_dd_sch_wing_mini_ab.stl
STLs/essentials/Gantry/X_Axis/X_Carriage/mini_AB_parts/printed_parts_MGN12_v4 - mini_ab - front.stl
STLs/essentials/Gantry/X_Axis/X_Carriage/mini_AB_parts/printed_parts_MGN12_v4 - mini_ab - guidler.stl
STLs/essentials/Gantry/X_Axis/X_Carriage/mini_AB_parts/printed_parts_MGN12_v4 - mini_ab - latch.stl
STLs/essentials/Gantry/X_Axis/X_Carriage/mini_AB_parts/printed_parts_MGN12_v4 - mini_ab - latch_shuttle.stl
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

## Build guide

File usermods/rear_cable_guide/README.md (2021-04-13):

Trimp pieces and guide for the rear umbilical cable.   By @aku

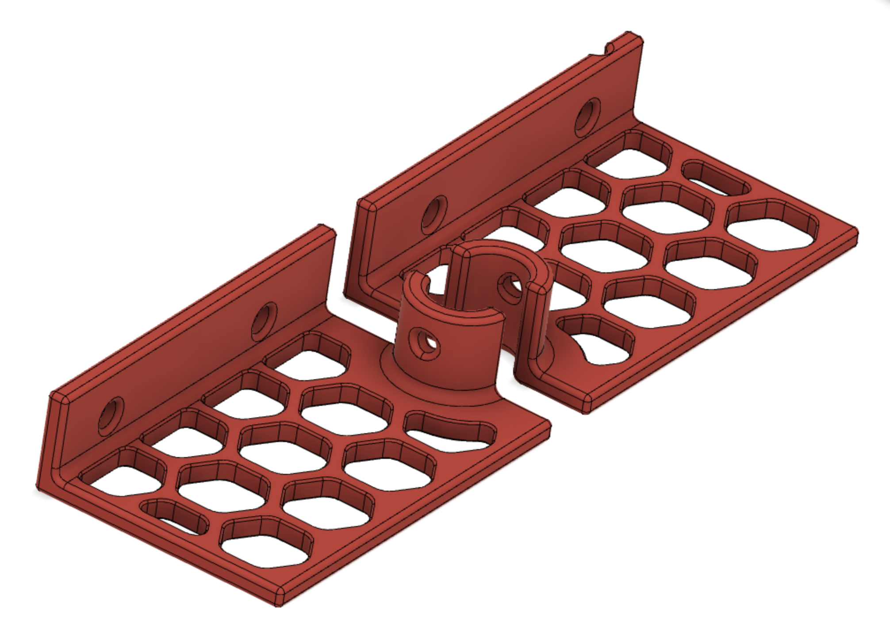
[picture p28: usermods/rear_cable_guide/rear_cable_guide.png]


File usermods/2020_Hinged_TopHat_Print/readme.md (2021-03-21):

DON'T USE THESE YET.  THEY ARE NOT SIZED FOR TINYM.

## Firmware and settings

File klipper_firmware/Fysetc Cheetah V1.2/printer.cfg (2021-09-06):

# This file contains common pin mappings for the Fysetc Cheetah v1.2b
# board. To use this config, the firmware should be compiled for the
# STM32F103 with "No bootloader" and serial (on USART1 PA10/PA9)
# communication.

# The "make flash" command does not work on the Cheetah. Instead,
# after running "make", run the following command to flash the board:
#  stm32flash -w out/klipper.bin -v -i rts,-dtr,dtr /dev/ttyUSB0

# See docs/Config_Reference.md for a description of parameters.


[mcu]
serial: /dev/serial/by-id/usb-1a86_USB2.0-Serial-if00-port0
restart_method: cheetah

[stepper_x]
step_pin: PB8
dir_pin: !PB9
enable_pin: !PA8
microsteps: 16
full_steps_per_rotation: 400
rotation_distance: 40
endstop_pin: ^PA1
position_endstop: 153
position_max: 154
position_min: -3
homing_speed: 50

[tmc2208 stepper_x]
uart_pin: PA12
tx_pin: PA11
run_current: 1.00
hold_current: 0.500
stealthchop_threshold: 999999

[stepper_y]
step_pin: PB2
dir_pin: !PB3
enable_pin: !PB1
microsteps: 16
full_steps_per_rotation: 400
rotation_distance: 40
endstop_pin: ^PB4
position_endstop: 152.5
position_max: 152.5
position_min:-3
homing_speed: 50

[tmc2208 stepper_y]
uart_pin: PB7
tx_pin: PB6
run_current: 1.00
hold_current: 0.500
stealthchop_threshold: 999999

[stepper_z]
step_pin: PC0
dir_pin: PC1
enable_pin: !PC2
microsteps: 16
full_steps_per_rotation: 400
rotation_distance: 4
endstop_pin: ^PA15
#position_endstop: 0
position_max: 140
position_min: -3
homing_speed: 50

[tmc2208 stepper_z]
uart_pin: PB11
tx_pin: PB10
run_current: 1.00
hold_current: 0.500
stealthchop_threshold: 999999

[extruder]
step_pin: PC15
dir_pin: !PC14
enable_pin: !PC13
microsteps: 16
full_steps_per_rotation: 200 
rotation_distance: 4.077670766928368
nozzle_diameter: 0.400
filament_diameter: 1.750
heater_pin: PC6
sensor_type: EPCOS 100K B57560G104F
sensor_pin: PC4
#control: pid
#pid_kp: 21.527
#pid_ki: 1.063
#pid_kd: 108.982
min_temp: 0
max_temp: 270
max_extrude_only_distance: 780.0
max_extrude_cross_section: .8
Pressure_advance: 0.04665
pressure_advance_smooth_time: 0.040

[tmc2208 extruder]
uart_pin: PA3
tx_pin: PA2
run_current: 0.30
hold_current: 0.250
stealthchop_threshold: 999999

[heater_bed]
heater_pin: PC7
sensor_type: NTC 100K MGB18-104F39050L32
sensor_pin: PC5
#control: pid
#pid_kp: 54.027
#pid_ki: 0.770
#pid_kd: 948.182
min_temp: 0
max_temp: 130

[fan]
pin: PC8

[heater_fan nozzle_cooling_fan]
pin: PB0

[idle_timeout]
timeout: 180000

[homing_override]
axes: xyz
set_position_z: 0
gcode:
   G90
   G0 Z5 F600
   G28 X Y
   G0 X153 Y132 F3600 
   
   G28 Z
   G0 Z10 F1800
   G0 X75 Y75 Z20 F3600


[virtual_sdcard]
path: ~/uploads/

[pause_resume]

[display_status]

[gcode_macro CANCEL_PRINT]
rename_existing: BASE_CANCEL_PRINT
gcode:
    TURN_OFF_HEATERS
    CLEAR_PAUSE
    SDCARD_RESET_FILE
    BASE_CANCEL_PRINT

[gcode_macro CANCEL_PRINT]
rename_existing: BASE_CANCEL_PRINT
gcode:
    TURN_OFF_HEATERS
    CLEAR_PAUSE
    SDCARD_RESET_FILE
    BASE_CANCEL_PRINT

[gcode_macro PRINT_START]
#   Use PRINT_START for the slicer starting script - please customise for your slicer of choice
gcode:
    M140 S{BED}
    G28                            ; home all axes
    G1 Z20 F3000                   ; move nozzle away from bed
    # Wait for bed to reach temperature
    M190 S{BED}
    # Set and wait for nozzle to reach temperature
    M109 S{EXTRUDER}


   
[gcode_macro PRINT_END]
#   Use PRINT_END for the slicer ending script - please customise for your slicer of choice
gcode:

    M400                           ; wait for buffer to clear
    G92 E0                         ; zero the extruder
    G1 E-4.0 F3600                 ; retract filament
    G91                            ; relative positioning

    #   Get Boundaries
    {% set max_x = printer.configfile.config["stepper_x"]["position_max"]|float %}
    {% set max_y = printer.configfile.config["stepper_y"]["position_max"]|float %}
    {% set max_z = printer.configfile.config["stepper_z"]["position_max"]|float %}

    #   Check end position to determine safe direction to move
    {% if printer.toolhead.position.x < (max_x - 20) %}
        {% set x_safe = 20.0 %}
    {% else %}
        {% set x_safe = -20.0 %}
    {% endif %}

    {% if printer.toolhead.position.y < (max_y - 20) %}
        {% set y_safe = 20.0 %}
    {% else %}
        {% set y_safe = -20.0 %}
    {% endif %}

    {% if printer.toolhead.position.z < (max_z - 2) %}
        {% set z_safe = 2.0 %}
    {% else %}
        {% set z_safe = max_z - printer.toolhead.position.z %}
    {% endif %}

    G0 Z{z_safe} F3600    ; move nozzle up
    G0 X{x_safe} Y{y_safe} F20000    ; move nozzle to remove stringing
    TURN_OFF_HEATERS
    M107                           ; turn off fan
    G90                            ; absolute positioning
    G0 X75 Y{max_y} F3600          ; park nozzle at rear


[printer]
kinematics: corexy
max_velocity: 500
max_accel: 5000
max_z_velocity: 5
max_z_accel: 100

[board_pins]
aliases:
    # EXP1 header
    EXP1_1=PC9,  EXP1_3=PC11, EXP1_5=PC10, EXP1_7=PB12, EXP1_9=<GND>,
    EXP1_2=PC12, EXP1_4=PB14, EXP1_6=PB13, EXP1_8=PB15, EXP1_10=<5V>
    # Pins EXP1_4, EXP1_8, EXP1_6 are also MISO, MOSI, SCK of bus "spi2"

# See the sample-lcd.cfg file for definitions of common LCD displays.

#*# <---------------------- SAVE_CONFIG ---------------------->
#*# DO NOT EDIT THIS BLOCK OR BELOW. The contents are auto-generated.
#*#
#*# [extruder]
#*# control = pid
#*# pid_kp = 22.562
#*# pid_ki = 0.912
#*# pid_kd = 139.601
#*#
#*# [heater_bed]
#*# control = pid
#*# pid_kp = 58.047
#*# pid_ki = 3.172
#*# pid_kd = 265.564
#*#
#*# [stepper_z]
#*# position_endstop = -0.700
#*#
#*# [input_shaper]
#*# shaper_type_x = ei
#*# shaper_freq_x = 84.0
#*# shaper_type_y = zv
#*# shaper_freq_y = 71.8

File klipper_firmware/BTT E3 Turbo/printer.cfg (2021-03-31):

# This file contains common pin mappings for the BIGTREETECH SKR E3
# Turbo. To use this config, the firmware should be compiled for the
# LPC1769.

# See docs/Config_Reference.md for a description of parameters.

[stepper_x]
step_pin: P1.4
dir_pin: !P1.8
enable_pin: !P1.0
microsteps: 16
full_steps_per_rotation: 400
rotation_distance: 40
endstop_pin: ^P1.29
position_endstop: 153
position_max: 154
position_min: -3
homing_speed: 50

[tmc2209 stepper_x]
uart_pin: P1.1
#diag_pin: P1.29
run_current: 1.0
hold_current: 0.800
stealthchop_threshold: 99999

[stepper_y]
step_pin: P1.14
dir_pin: !P1.15
enable_pin: !P1.9
microsteps: 16
full_steps_per_rotation: 400
rotation_distance: 40
endstop_pin: ^P1.28
position_endstop: 152.5
position_max: 152.5
position_min:-3
homing_speed: 50

[tmc2209 stepper_y]
uart_pin: P1.10
#diag_pin: P1.28
run_current: 1.0
hold_current: 0.800
stealthchop_threshold: 99999

[stepper_z]
step_pin: P4.29
dir_pin: P4.28
enable_pin: !P1.16
microsteps: 16
full_steps_per_rotation: 400
rotation_distance: 4
endstop_pin: ^P1.27
position_endstop: -.95
position_max: 140
position_min: -1
homing_speed: 10

[tmc2209 stepper_z]
uart_pin: P1.17
#diag_pin: P1.27
run_current: 1.0
hold_current: 0.800
stealthchop_threshold: 99999

[extruder]
step_pin: P2.6
dir_pin: !P2.7
enable_pin: !P0.4
microsteps: 16
full_steps_per_rotation: 400
rotation_distance: 8.28121601732
nozzle_diameter: 0.400
filament_diameter: 1.750
heater_pin: P2.3
sensor_type: EPCOS 100K B57560G104F
sensor_pin: P0.24
#control: pid
#pid_Kp: 21.527
#pid_Ki: 1.063
#pid_Kd: 108.982
min_temp: 0
max_temp: 270
max_extrude_only_distance: 780.0
max_extrude_cross_section: .8
Pressure_advance: 0.04
pressure_advance_smooth_time: 0.040

[tmc2209 extruder]
uart_pin: P0.5
#diag_pin: P1.26
run_current: 0.30
hold_current: 0.250
stealthchop_threshold: 99999


[heater_bed]
heater_pin: P2.5
#keenovo pad
sensor_type:  NTC 100K MGB18-104F39050L32  
sensor_pin: P0.25
smooth_time: 3.0
max_power: 0.8
#control: pid
#pid_Kp: 54.027
#pid_Ki: 0.770
#pid_Kd: 948.182
min_temp: 0
max_temp: 130

[fan]
pin: P2.2

[heater_fan nozzle_cooling_fan]
pin: P2.1

[idle_timeout]
timeout: 180000

[homing_override]
axes: xyz
set_position_z: 0
gcode:
   G90
   G0 Z5 F600
   G28 X Y
   G0 X153 Y132 F3600 
   
   G28 Z
   G0 Z10 F1800
   G0 X75 Y75 Z20 F3600

[mcu]
serial: /dev/serial/by-id/usb-Klipper_lpc1769_1680FF01A49869AFACCE3E5EC02000F5-if00

[printer]
kinematics: corexy
max_velocity: 500
max_accel: 2000
max_z_velocity: 10
max_z_accel: 30
square_corner_velocity: 5.0

[virtual_sdcard]
path: ~/uploads/

[pause_resume]

[display_status]

[gcode_macro CANCEL_PRINT]
rename_existing: BASE_CANCEL_PRINT
gcode:
    TURN_OFF_HEATERS
    CLEAR_PAUSE
    SDCARD_RESET_FILE
    BASE_CANCEL_PRINT

[gcode_macro PRINT_START]
#   Use PRINT_START for the slicer starting script - please customise for your slicer of choice
gcode:
    M140 S{BED}
    G28                            ; home all axes
    G1 Z20 F3000                   ; move nozzle away from bed
    # Wait for bed to reach temperature
    M190 S{BED}
    # Set and wait for nozzle to reach temperature
    M109 S{EXTRUDER}


   
[gcode_macro PRINT_END]
#   Use PRINT_END for the slicer ending script - please customise for your slicer of choice
gcode:

    M400                           ; wait for buffer to clear
    G92 E0                         ; zero the extruder
    G1 E-4.0 F3600                 ; retract filament
    G91                            ; relative positioning

    #   Get Boundaries
    {% set max_x = printer.configfile.config["stepper_x"]["position_max"]|float %}
    {% set max_y = printer.configfile.config["stepper_y"]["position_max"]|float %}
    {% set max_z = printer.configfile.config["stepper_z"]["position_max"]|float %}

    #   Check end position to determine safe direction to move
    {% if printer.toolhead.position.x < (max_x - 20) %}
        {% set x_safe = 20.0 %}
    {% else %}
        {% set x_safe = -20.0 %}
    {% endif %}

    {% if printer.toolhead.position.y < (max_y - 20) %}
        {% set y_safe = 20.0 %}
    {% else %}
        {% set y_safe = -20.0 %}
    {% endif %}

    {% if printer.toolhead.position.z < (max_z - 2) %}
        {% set z_safe = 2.0 %}
    {% else %}
        {% set z_safe = max_z - printer.toolhead.position.z %}
    {% endif %}

    G0 Z{z_safe} F3600    ; move nozzle up
    G0 X{x_safe} Y{y_safe} F20000    ; move nozzle to remove stringing
    TURN_OFF_HEATERS
    M107                           ; turn off fan
    G90                            ; absolute positioning
    G0 X75 Y{max_y} F3600          ; park nozzle at rear
	
[gcode_macro LOAD_FILAMENT]
gcode:
   M83                            ; set extruder to relative
   G1 E280 F1800                  ; quickly load filament to down bowden
   G1 E30 F300                    ; slower extrusion for hotend path
   G1 E15 F150                    ; prime nozzle with filament
   M82                            ; set extruder to absolute
    
[gcode_macro UNLOAD_FILAMENT]
gcode:
   M83                            ; set extruder to relative
   G1 E10 F300                    ; extrude a little to soften tip
   G1 E-380 F1800                 ; retract filament completely
   M82                            ; set extruder to absolute
   
   
[gcode_macro PAUSE]
rename_existing: BASE_PAUSE
default_parameter_X: 230    # edit to your preferred park position
default_parameter_Y: 230    # edit to your preferred park position
default_parameter_Z: 10     # edit to your preferred park position
default_parameter_E: 1      # edit to your preferred retract length
gcode:
    SAVE_GCODE_STATE NAME=PAUSE_state
    BASE_PAUSE
    G91
    G1 E-{E} F2100
    G1 Z{Z}
    G90
    G1 X{X} Y{Y} F6000
    
[gcode_macro RESUME]
rename_existing: BASE_RESUME
default_parameter_E: 1      # edit to your preferred retract length
gcode:
    G91
    G1 E{E} F2100
    G90
    RESTORE_GCODE_STATE NAME=PAUSE_state MOVE=1
    BASE_RESUME


[static_digital_output tmc_standby_pins]
pins: !P3.26, !P3.25, !P1.18, !P1.19, !P2.13

[board_pins]
aliases:
    # EXP1 header
    EXP1_1=P2.8,  EXP1_3=P0.19, EXP1_5=P0.20, EXP1_7=P0.17, EXP1_9=<GND>,
    EXP1_2=P0.16, EXP1_4=<RST>, EXP1_6=P0.15, EXP1_8=P0.18, EXP1_10=<5V>

# See the sample-lcd.cfg file for definitions of common LCD displays.

#*# <---------------------- SAVE_CONFIG ---------------------->
#*# DO NOT EDIT THIS BLOCK OR BELOW. The contents are auto-generated.
#*#
#*# [extruder]
#*# control = pid
#*# pid_kp = 24.373
#*# pid_ki = 1.121
#*# pid_kd = 132.526
#*#
#*# [heater_bed]
#*# control = pid
#*# pid_kp = 47.300
#*# pid_ki = 1.855
#*# pid_kd = 301.539
